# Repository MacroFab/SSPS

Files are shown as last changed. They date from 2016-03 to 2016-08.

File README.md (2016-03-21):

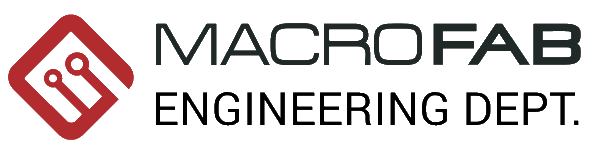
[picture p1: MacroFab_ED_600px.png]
MF_ED_Logo

***
###SSPS
***
**MacroFab, INC. Super Simple Power Supply**

This repository contains the information and files needed to build the Super Simple Power Supply or SSPS. 

More information can be found on the [MacroFab, INC. blog](https://macrofab.com/blog/tag/ssps/). 

***
**License Information**

This project is under the [Creative Commons Attribution-ShareAlike 4.0 International License](LICENSE.md). These files are provided with no warranty and should be used at your own risk. 

***

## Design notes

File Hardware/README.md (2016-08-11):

***
###Hardware
***
**Hardware for the Super Simple Power Supply**

This repository contains the information and files needed to build the Super Simple Power Supply or SSPS. 

More information can be found on the [MacroFab, INC. blog](https://macrofab.com/blog/tag/ssps/). Specifications can be found [here](https://macrofab.com/blog/super-simple-power-supply-ssps-design-part-1/).

***
**License Information**

This project is under the [Creative Commons Attribution-ShareAlike 4.0 International License](LICENSE.md). These files are provided with no warranty and should be used at your own risk. 

***
**Directory listing of the repository**

| Directory | Description |
|---|---|
| Datasheets |  Datasheets that are a pain to get a hold of. |
| Enclosure | Enclosure Drawings and Mockups. | 
| OPA541 Breakout | Test board for the OPA541 Opamp. |
| SSPS Front Panel | Front Panel for the SSPS. Digital Controls. |
| SSPS Front Panel Test | Test board for the SSPS digital side. |
| SSPS Analog board | Analog output board |
| SSPS Regulated Power Supply Simulation | Multisim Simulation of the SSPS Analog side. |

***
**Credits**

Designed by:   
Parker Dillmann 
Stephen "Hackerman" Kraig 

Software by:   
Parker Dillmann  
Stephen "Hackerman" Kraig 

***

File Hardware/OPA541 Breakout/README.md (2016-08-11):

###OPA541AP Breakout
***
**A simple breakout PCB for testing the OPA541 Opamp**

***
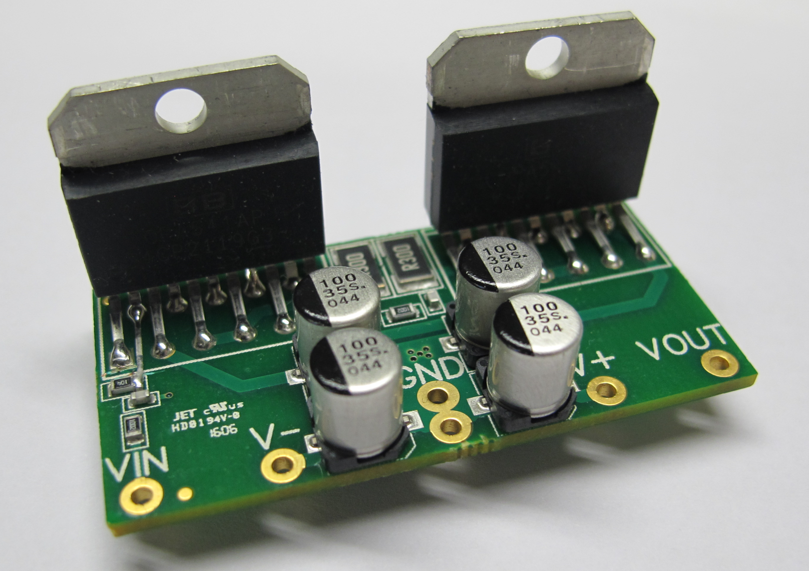
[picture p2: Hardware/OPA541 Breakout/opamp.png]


***
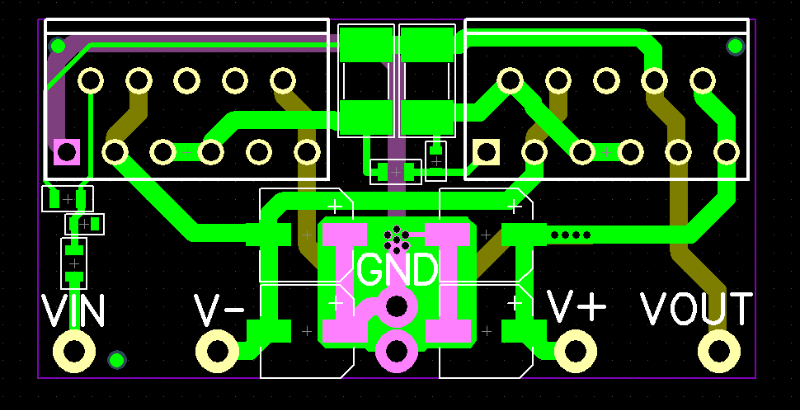
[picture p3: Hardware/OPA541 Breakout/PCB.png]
Layout Image


***
Schematic Image

***
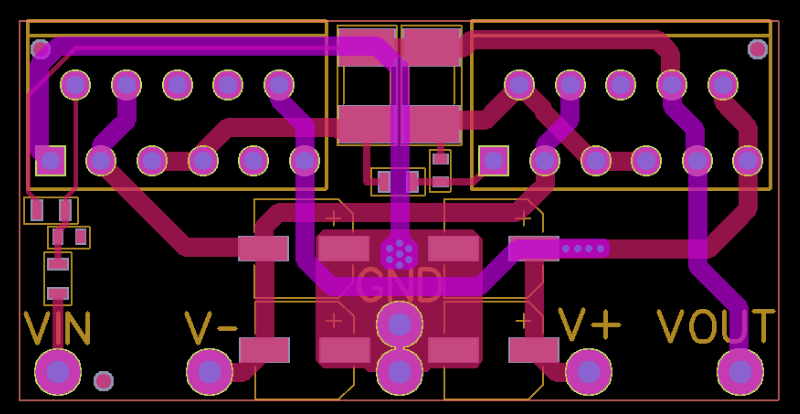
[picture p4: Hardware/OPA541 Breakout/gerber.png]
Gerber Top Drawing


Files are for Diptrace 2.4. Gerber files can be found in the Manufacturing Files directory. See main directory for licensing.

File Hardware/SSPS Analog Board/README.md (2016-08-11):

###SSPS Analog Output PCB
***
**The first revision of the analog output PCB for the SSPS**

***
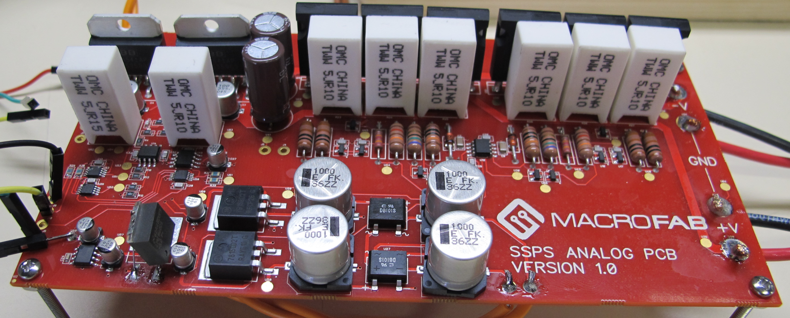
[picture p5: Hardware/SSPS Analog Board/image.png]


***
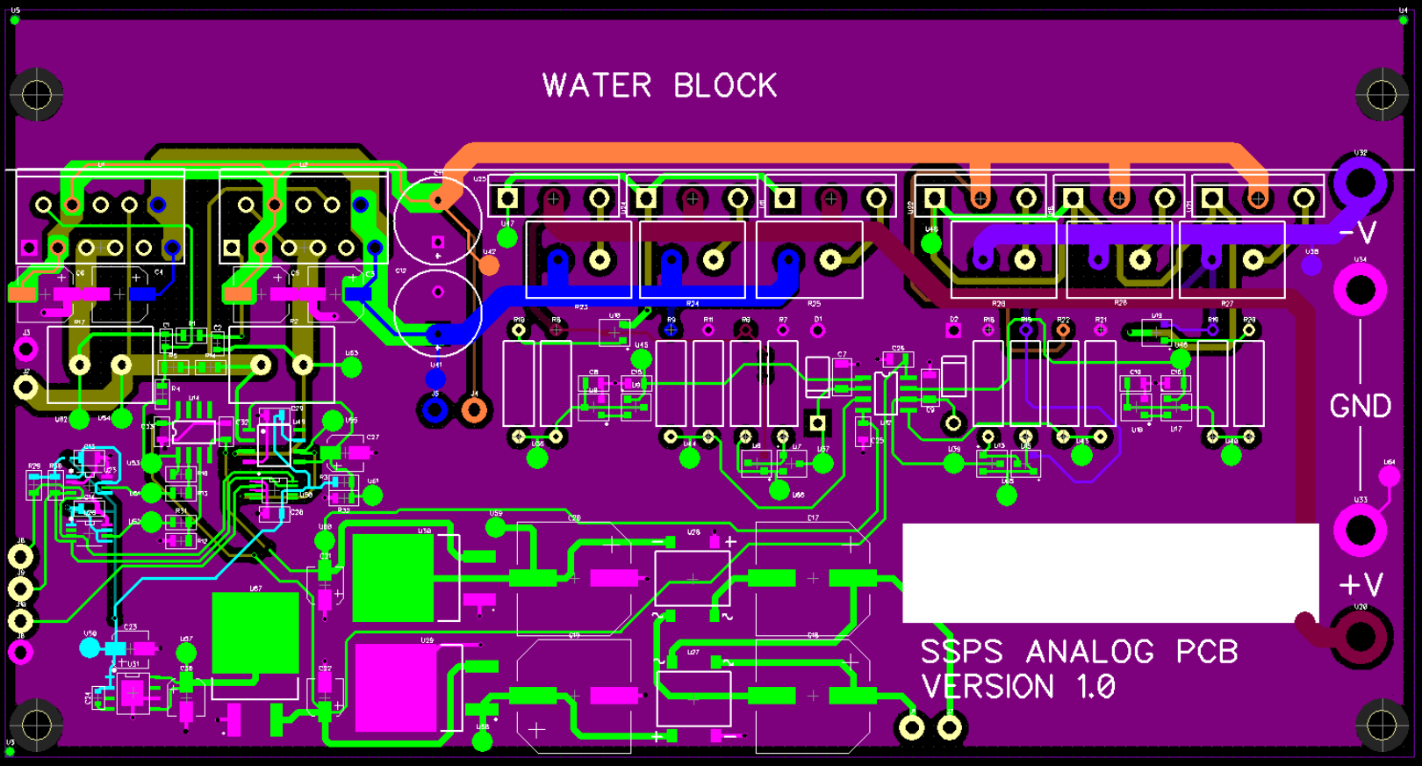
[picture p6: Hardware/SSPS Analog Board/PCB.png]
Layout Image


***
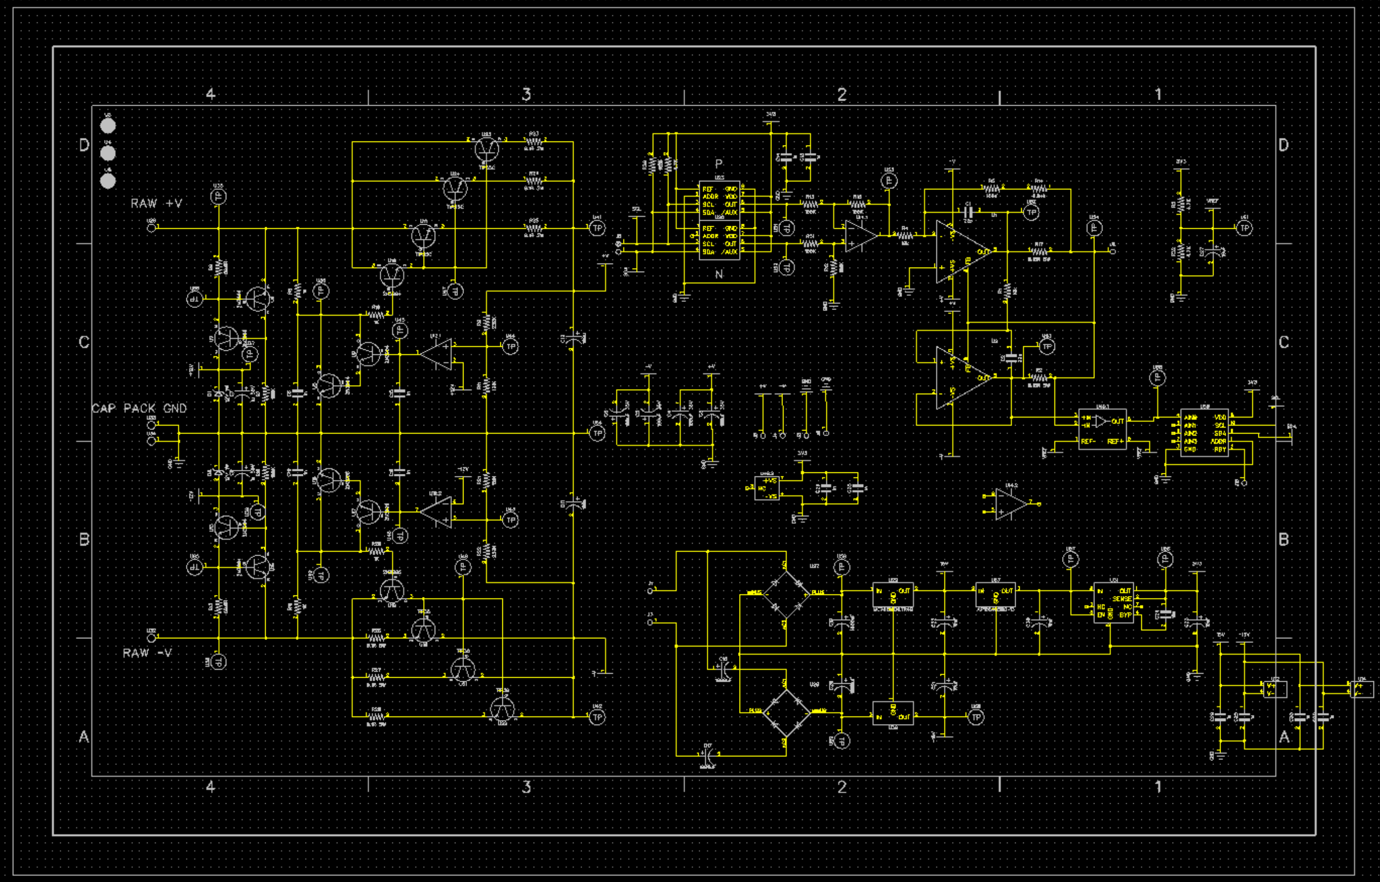
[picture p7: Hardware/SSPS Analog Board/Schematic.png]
Schematic Image


***
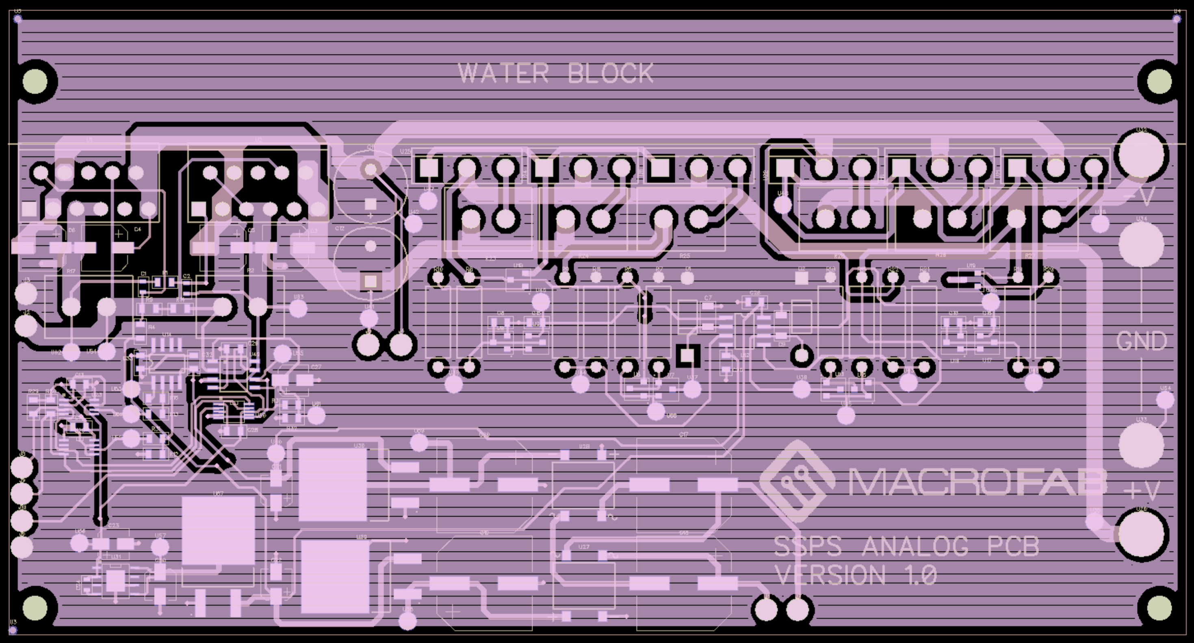
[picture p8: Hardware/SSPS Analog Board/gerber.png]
Gerber Top Drawing


Files are for Diptrace 2.4. Gerber files can be found in the Manufacturing Files directory. See main directory for licensing.

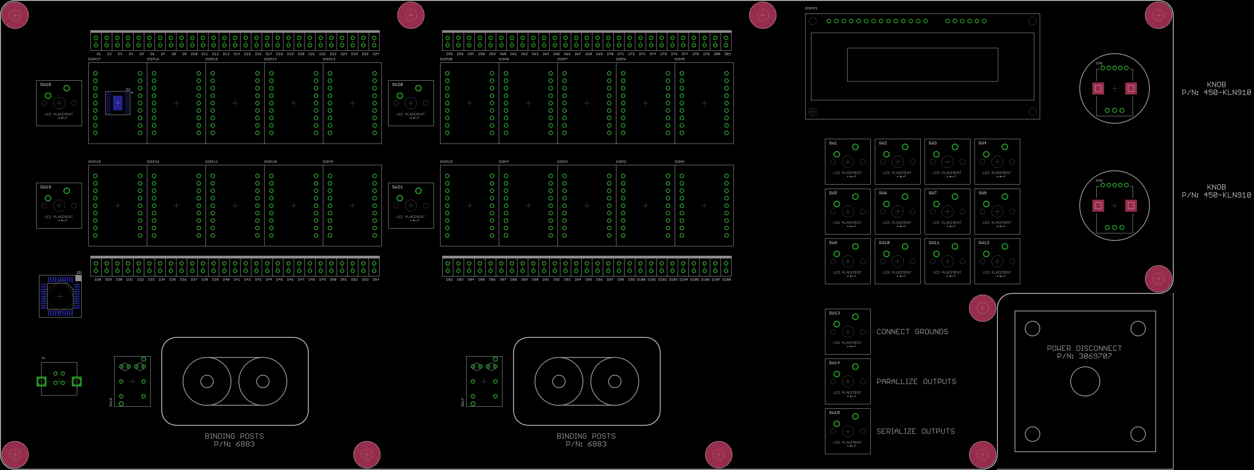
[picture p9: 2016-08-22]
Hardware/SSPS Front Panel/Layout.png

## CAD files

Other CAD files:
Hardware/SSPS Front Panel/SSPS Front Panel.dwg
Hardware/Enclosure/Enclosure.skp

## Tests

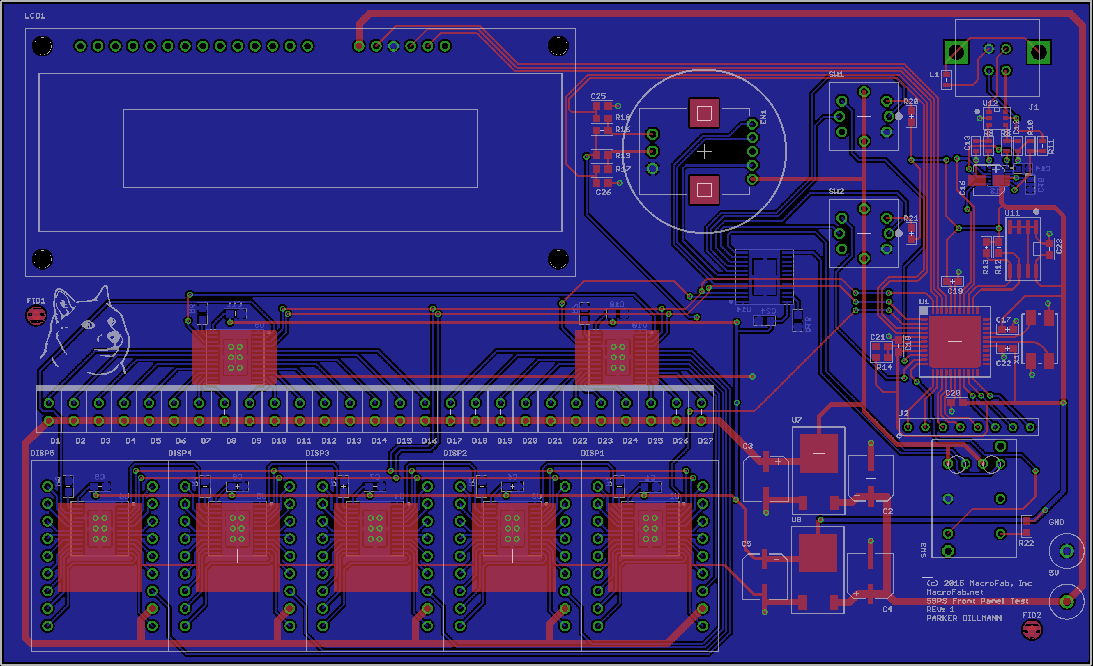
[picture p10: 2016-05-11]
Hardware/SSPS Front Panel Test/Layout.png

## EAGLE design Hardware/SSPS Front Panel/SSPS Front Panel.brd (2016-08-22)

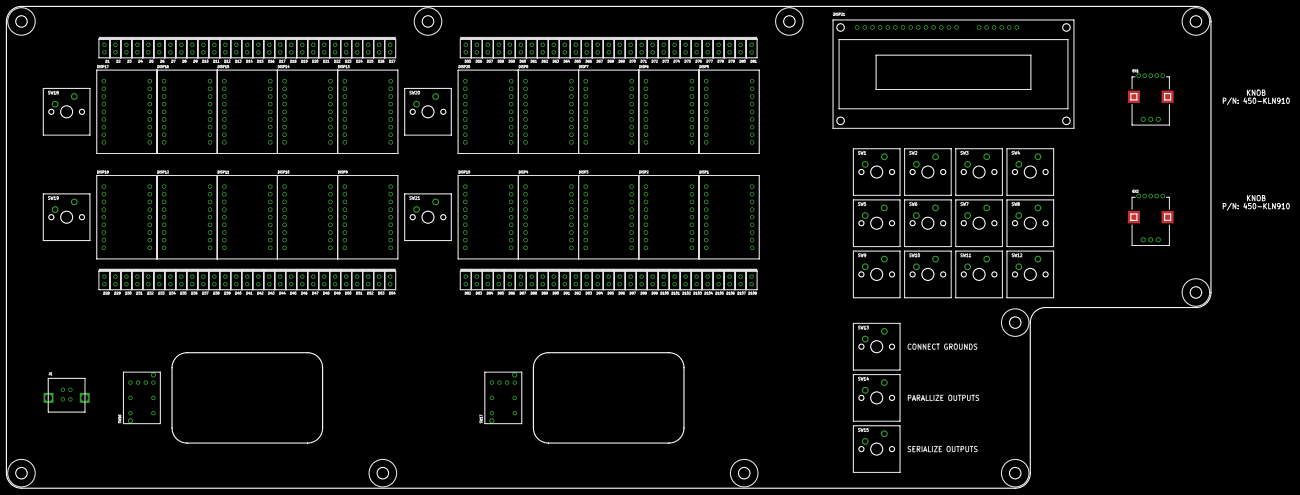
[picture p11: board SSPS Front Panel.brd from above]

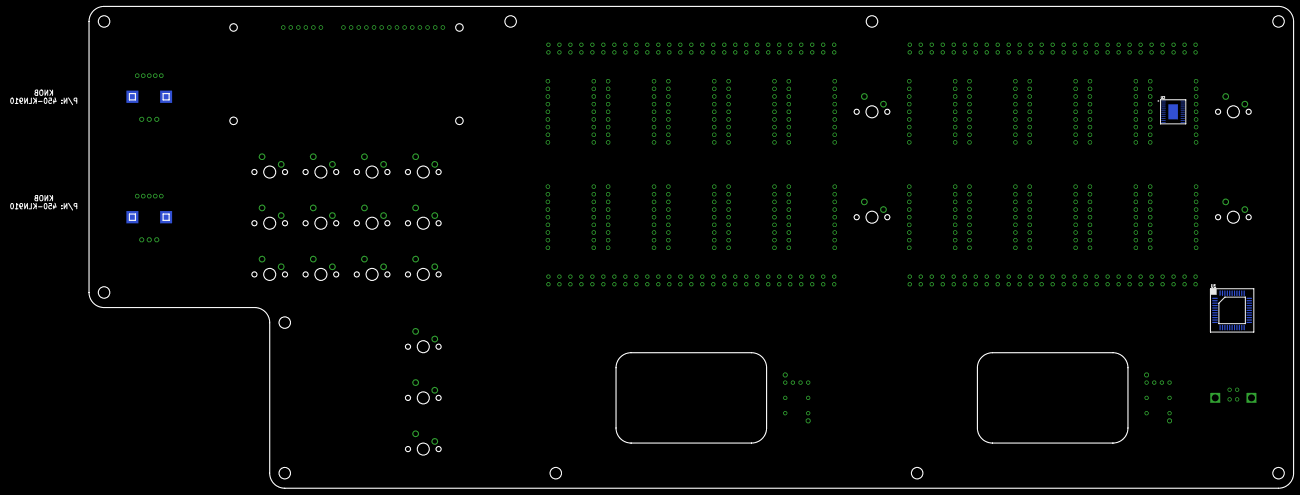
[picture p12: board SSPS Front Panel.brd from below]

Board: 2 copper layers, 400.0 x 160.0 mm, 165 parts (2 on the bottom side), 3 nets, no tracks yet.

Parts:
D1, D2, D3, D4, D5, D6, D7, D8, D9, D10, D11, D12, D13, D14, D15, D16, D17, D18, D19, D20, D21, D22, D23, D24, D25, D26, D27, D28, D29, D30, D31, D32, D33, D34, D35, D36, D37, D38, D39, D40, D41, D42, D43, D44, D45, D46, D47, D48, D49, D50, D51, D52, D53, D54, D55, D56, D57, D58, D59, D60, D61, D62, D63, D64, D65, D66, D67, D68, D69, D70, D71, D72, D73, D74, D75, D76, D77, D78, D79, D80, D81, D82, D83, D84, D85, D86, D87, D88, D89, D90, D91, D92, D93, D94, D95, D96, D97, D98, D99, D100, D101, D102, D103, D104, D105, D106, D107, D108: WP1043
DISP1, DISP2, DISP3, DISP4, DISP5, DISP6, DISP7, DISP8, DISP9, DISP10, DISP11, DISP12, DISP13, DISP14, DISP15, DISP16, DISP17, DISP18, DISP19, DISP20: PSA08-11GWA; PSA08-11SRWA
DISP21: CU16025-UWJ6; CU16025-UW6J
EN1, EN2: PEL12T-4226F-S1024; PEL12T
H1, H2, H3, H4, H5, H6, H7, H8, H9, H10: MOUNT_HOLE_150MIL
J1: 61400413321
SW1, SW2, SW3, SW4, SW5, SW6, SW7, SW8, SW9, SW10, SW11, SW12, SW13, SW14, SW15, SW18, SW19, SW20, SW21: MX1A
SW16, SW17: 5501
U1: P8X32A-Q44; LQFP44
U2: STP16CP05XTTR; STP16CP05XTTR_TTSOP-24

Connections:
SLD: J1.S1, J1.S2
VDD: U1.8, U1.18, U1.30, U1.40
VSS: U1.5, U1.17, U1.27, U1.39

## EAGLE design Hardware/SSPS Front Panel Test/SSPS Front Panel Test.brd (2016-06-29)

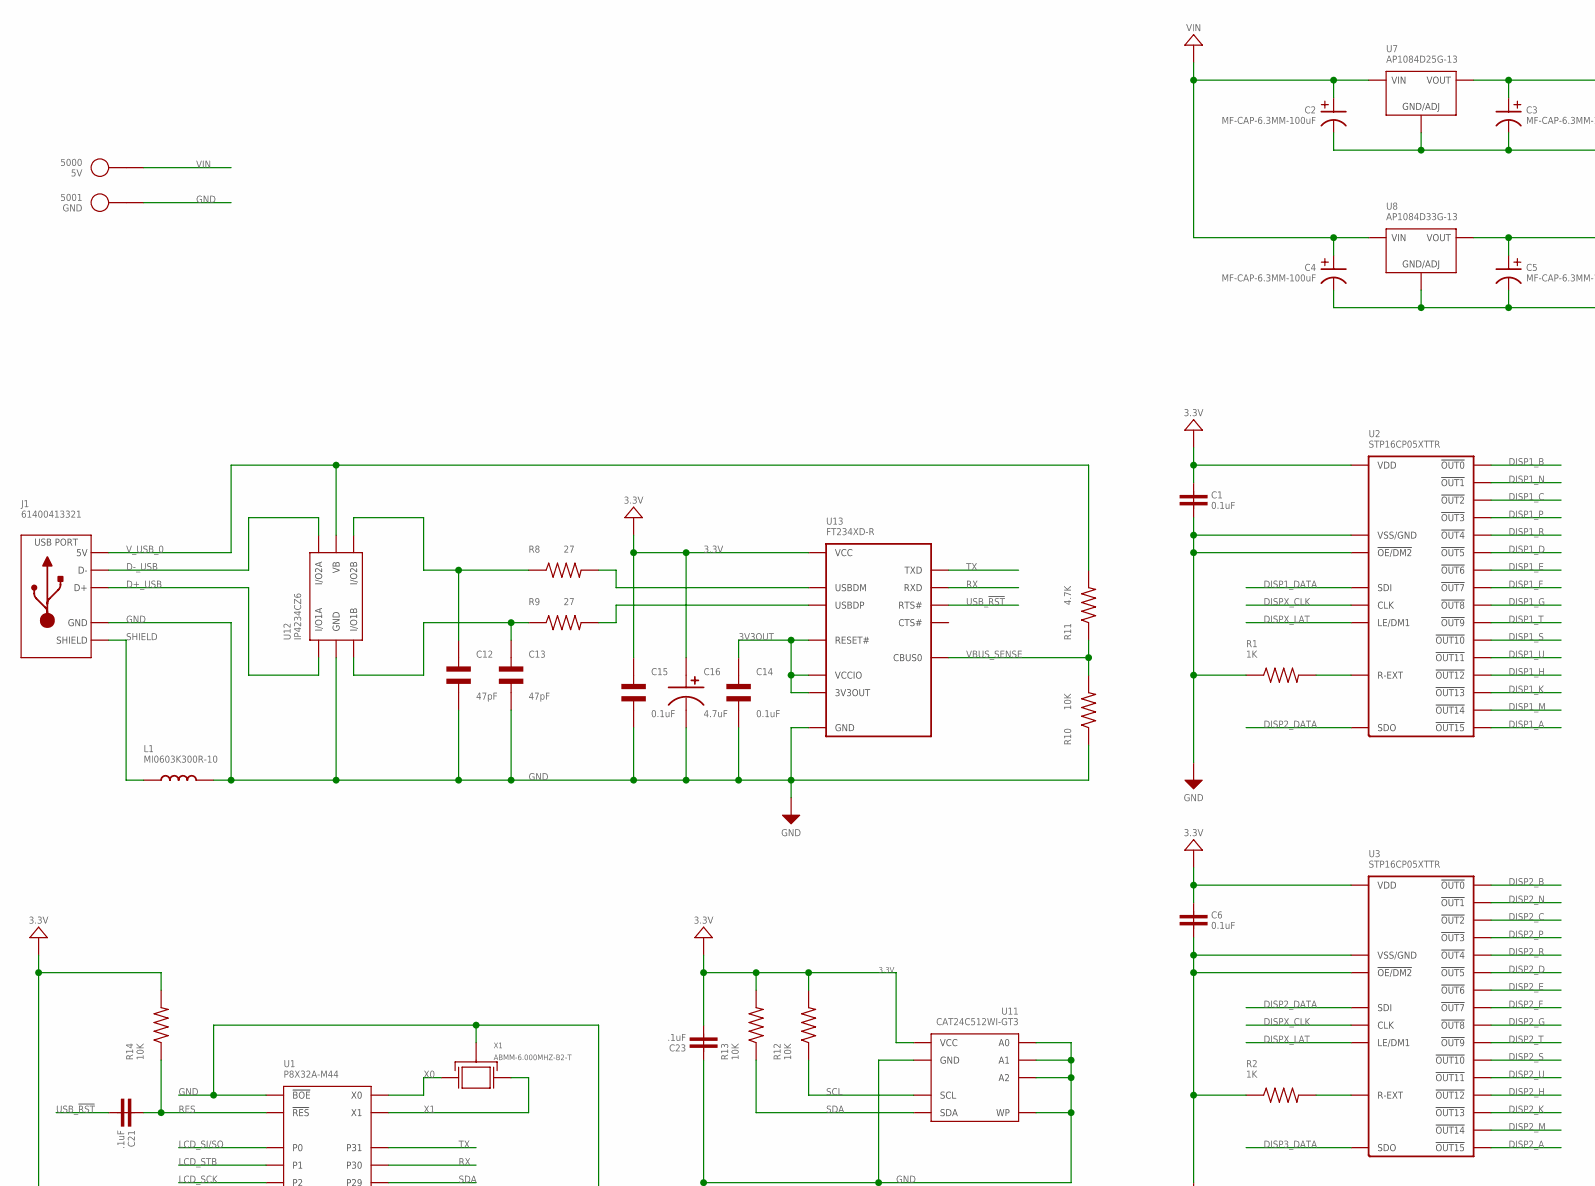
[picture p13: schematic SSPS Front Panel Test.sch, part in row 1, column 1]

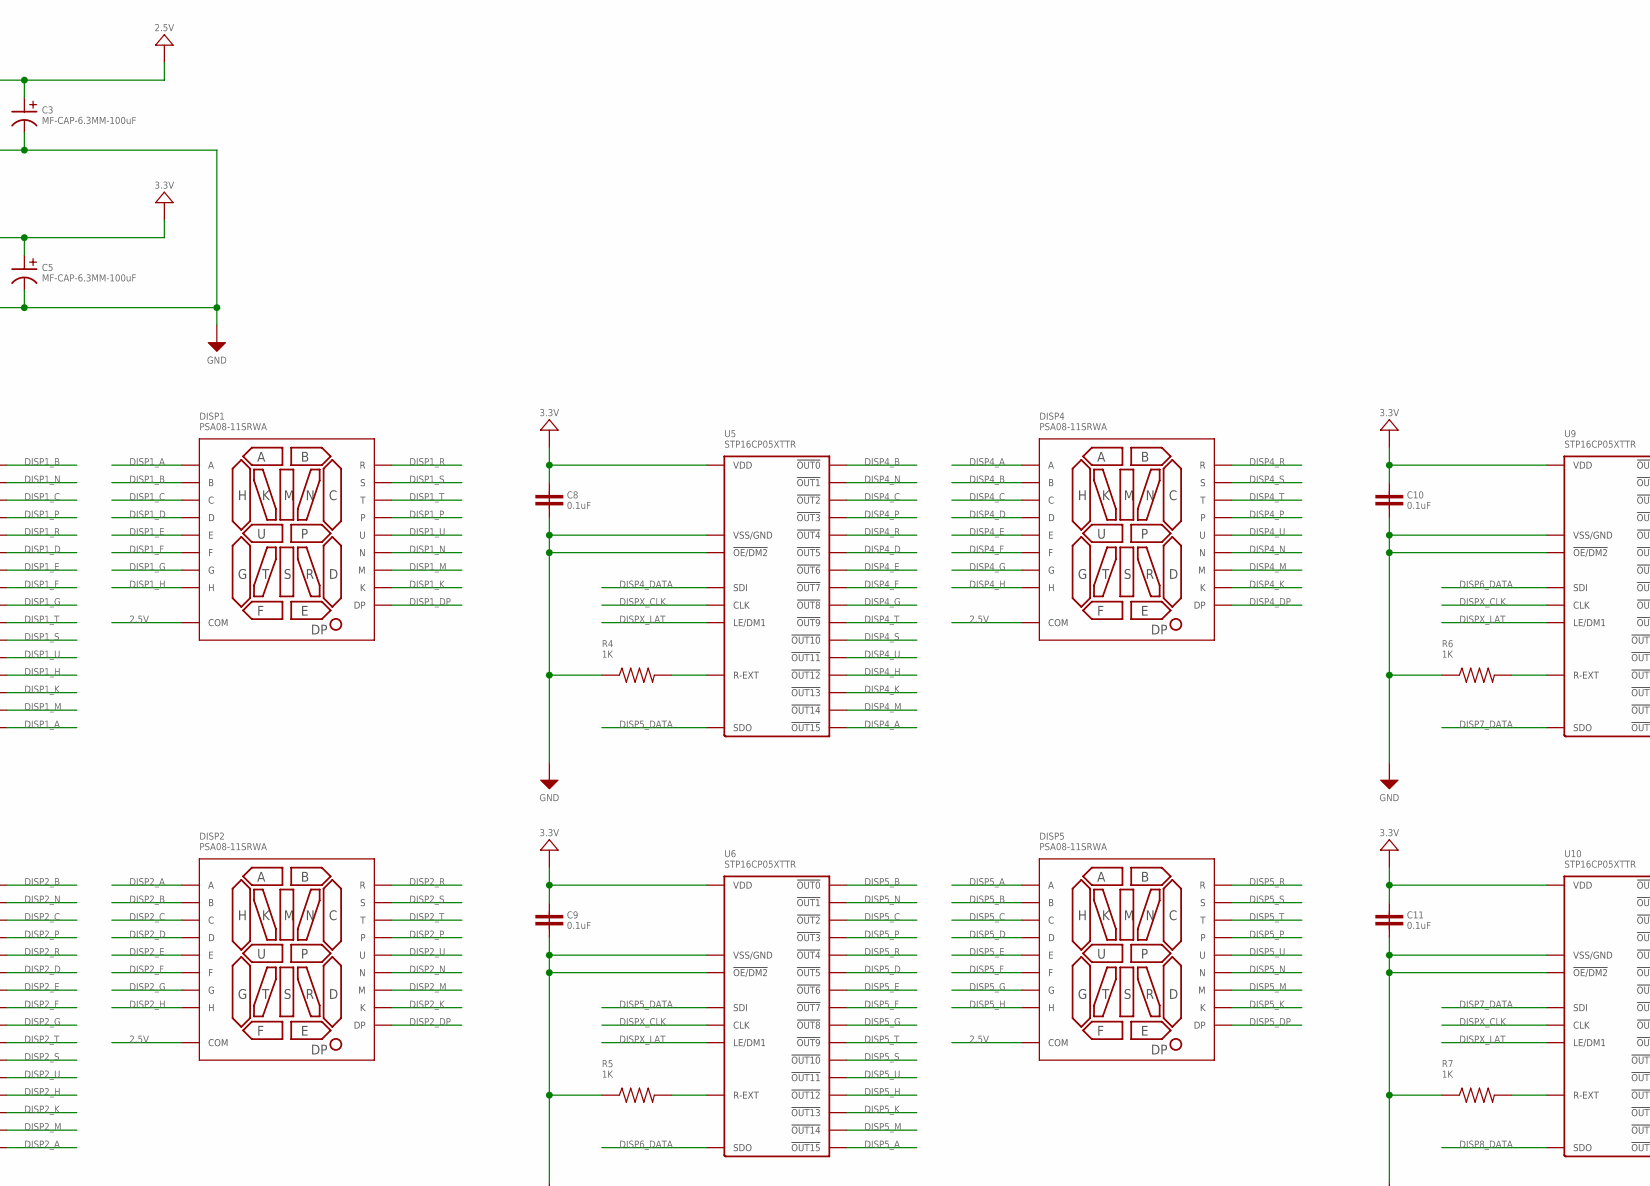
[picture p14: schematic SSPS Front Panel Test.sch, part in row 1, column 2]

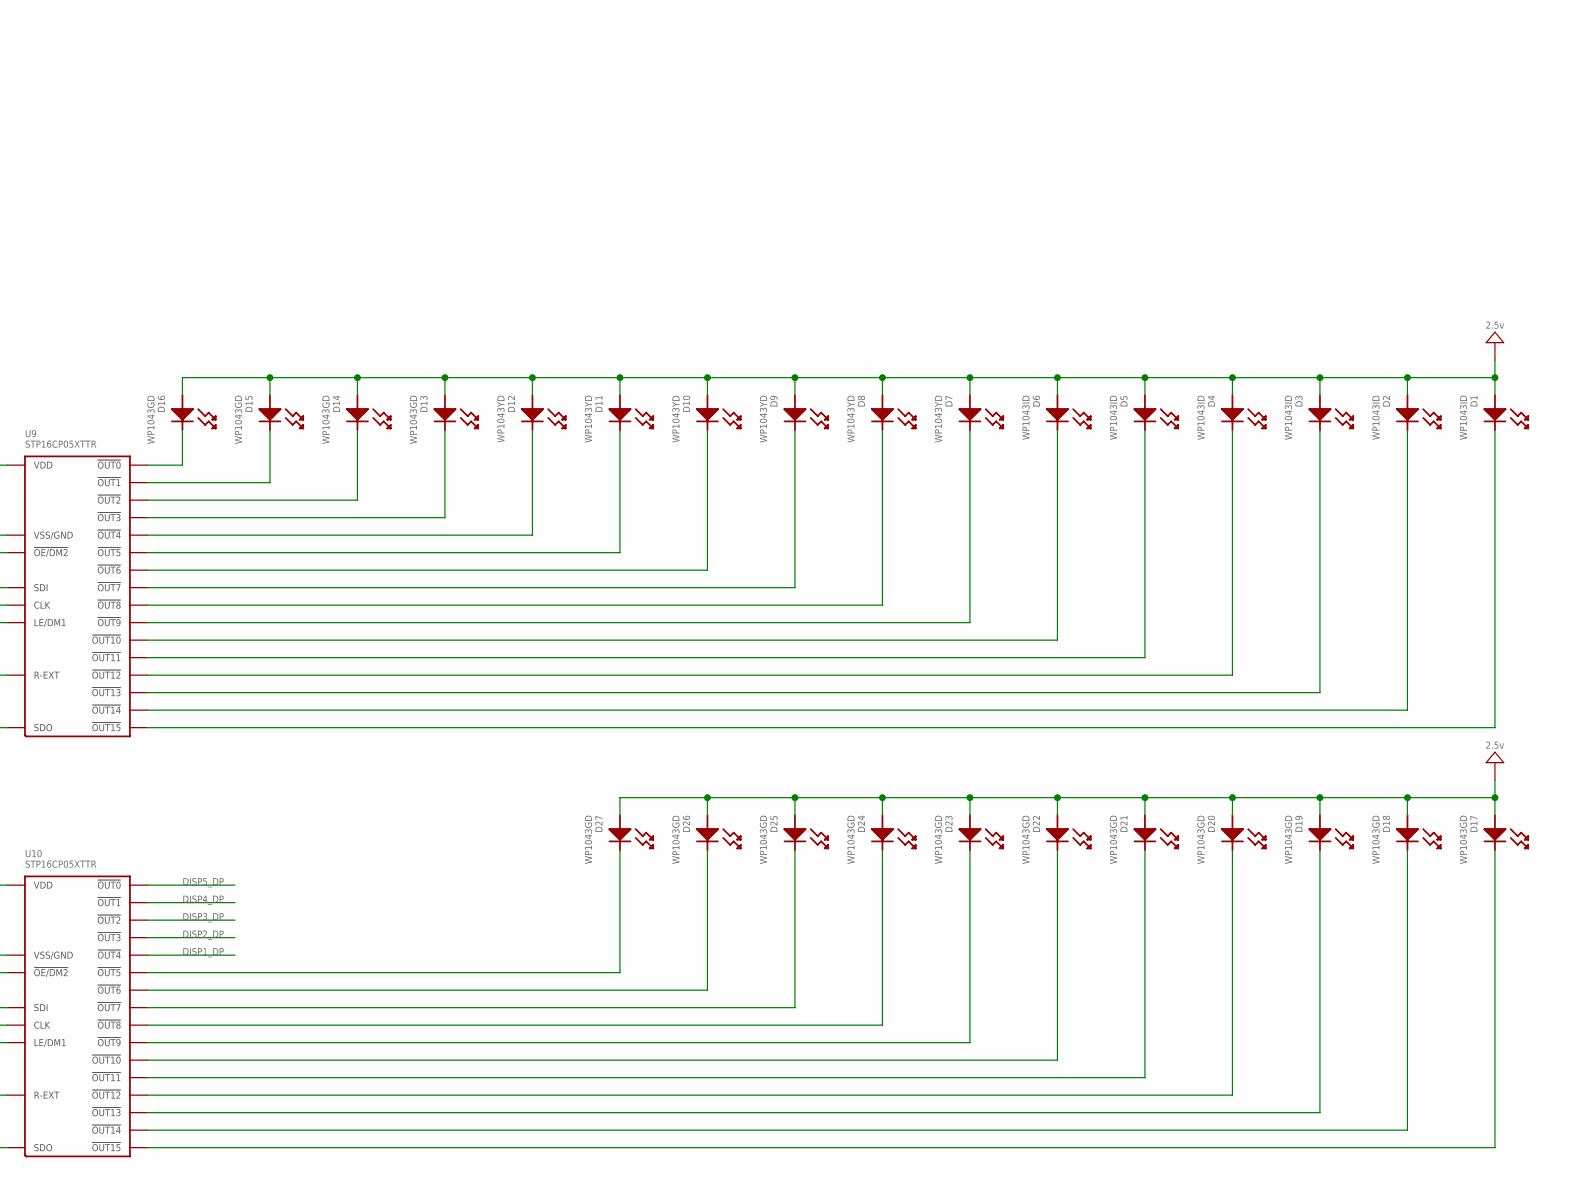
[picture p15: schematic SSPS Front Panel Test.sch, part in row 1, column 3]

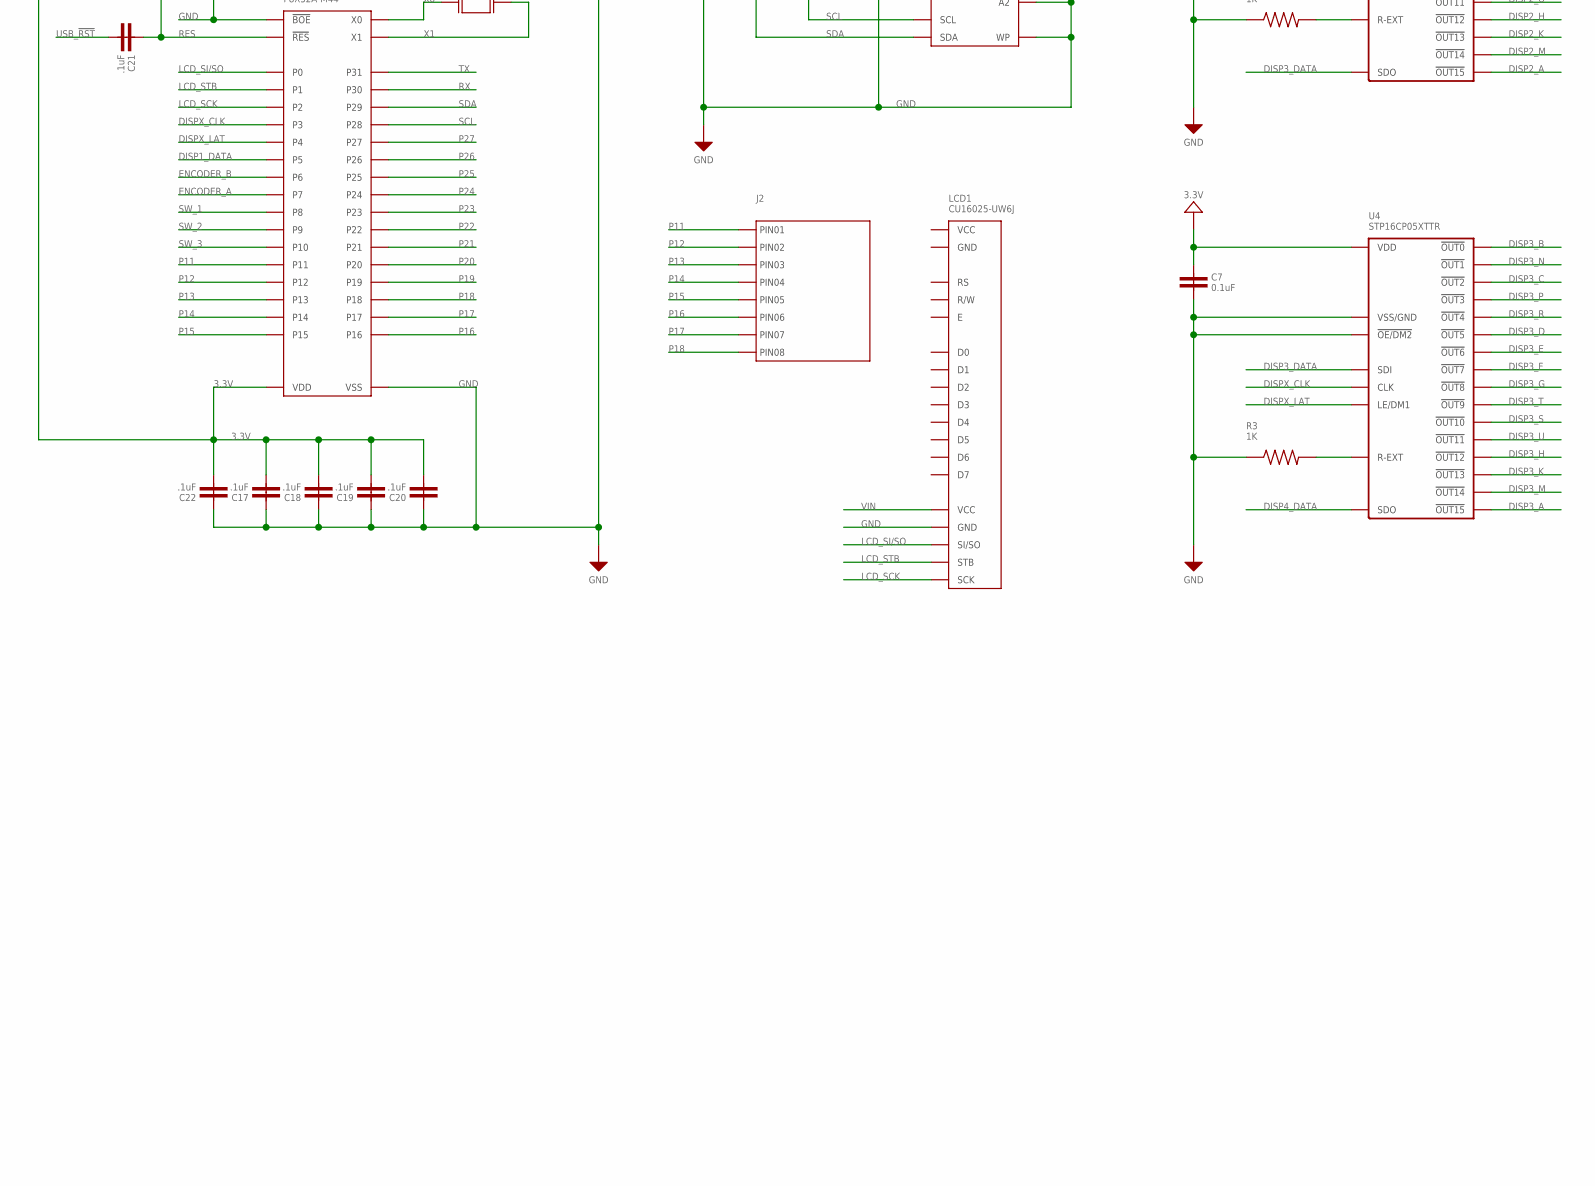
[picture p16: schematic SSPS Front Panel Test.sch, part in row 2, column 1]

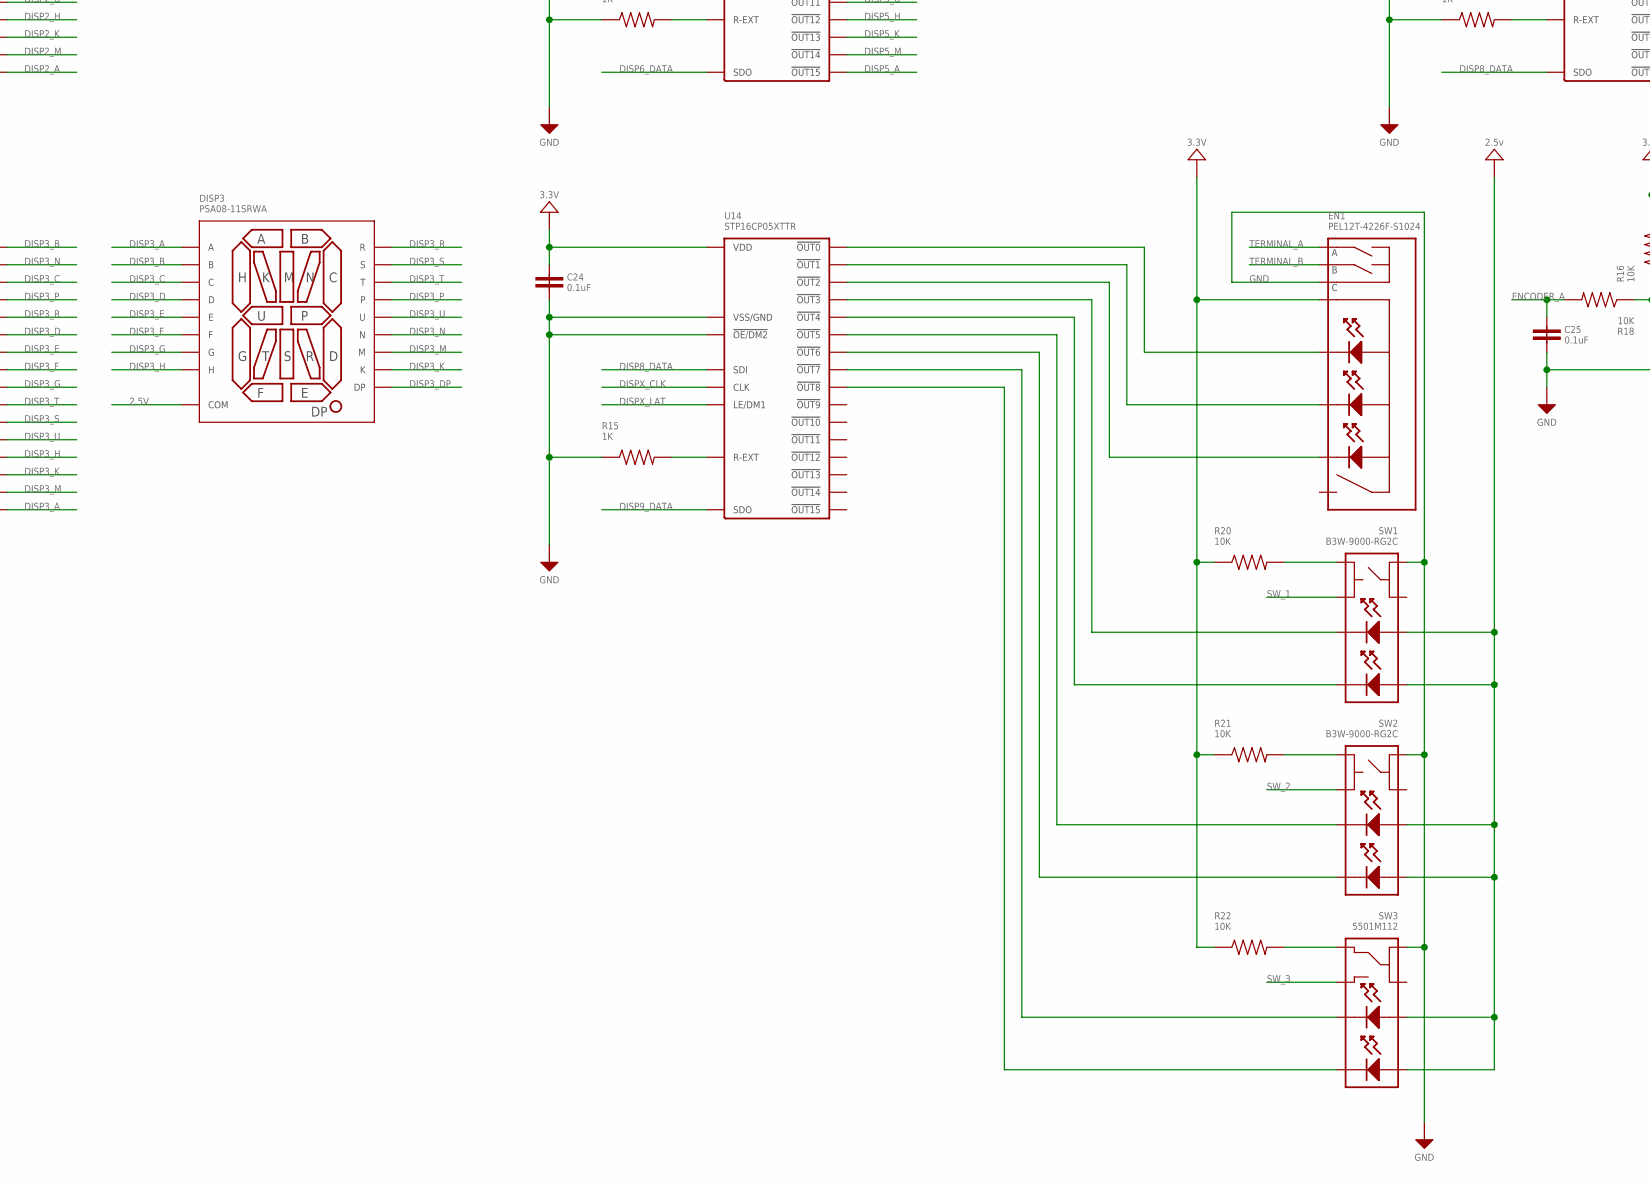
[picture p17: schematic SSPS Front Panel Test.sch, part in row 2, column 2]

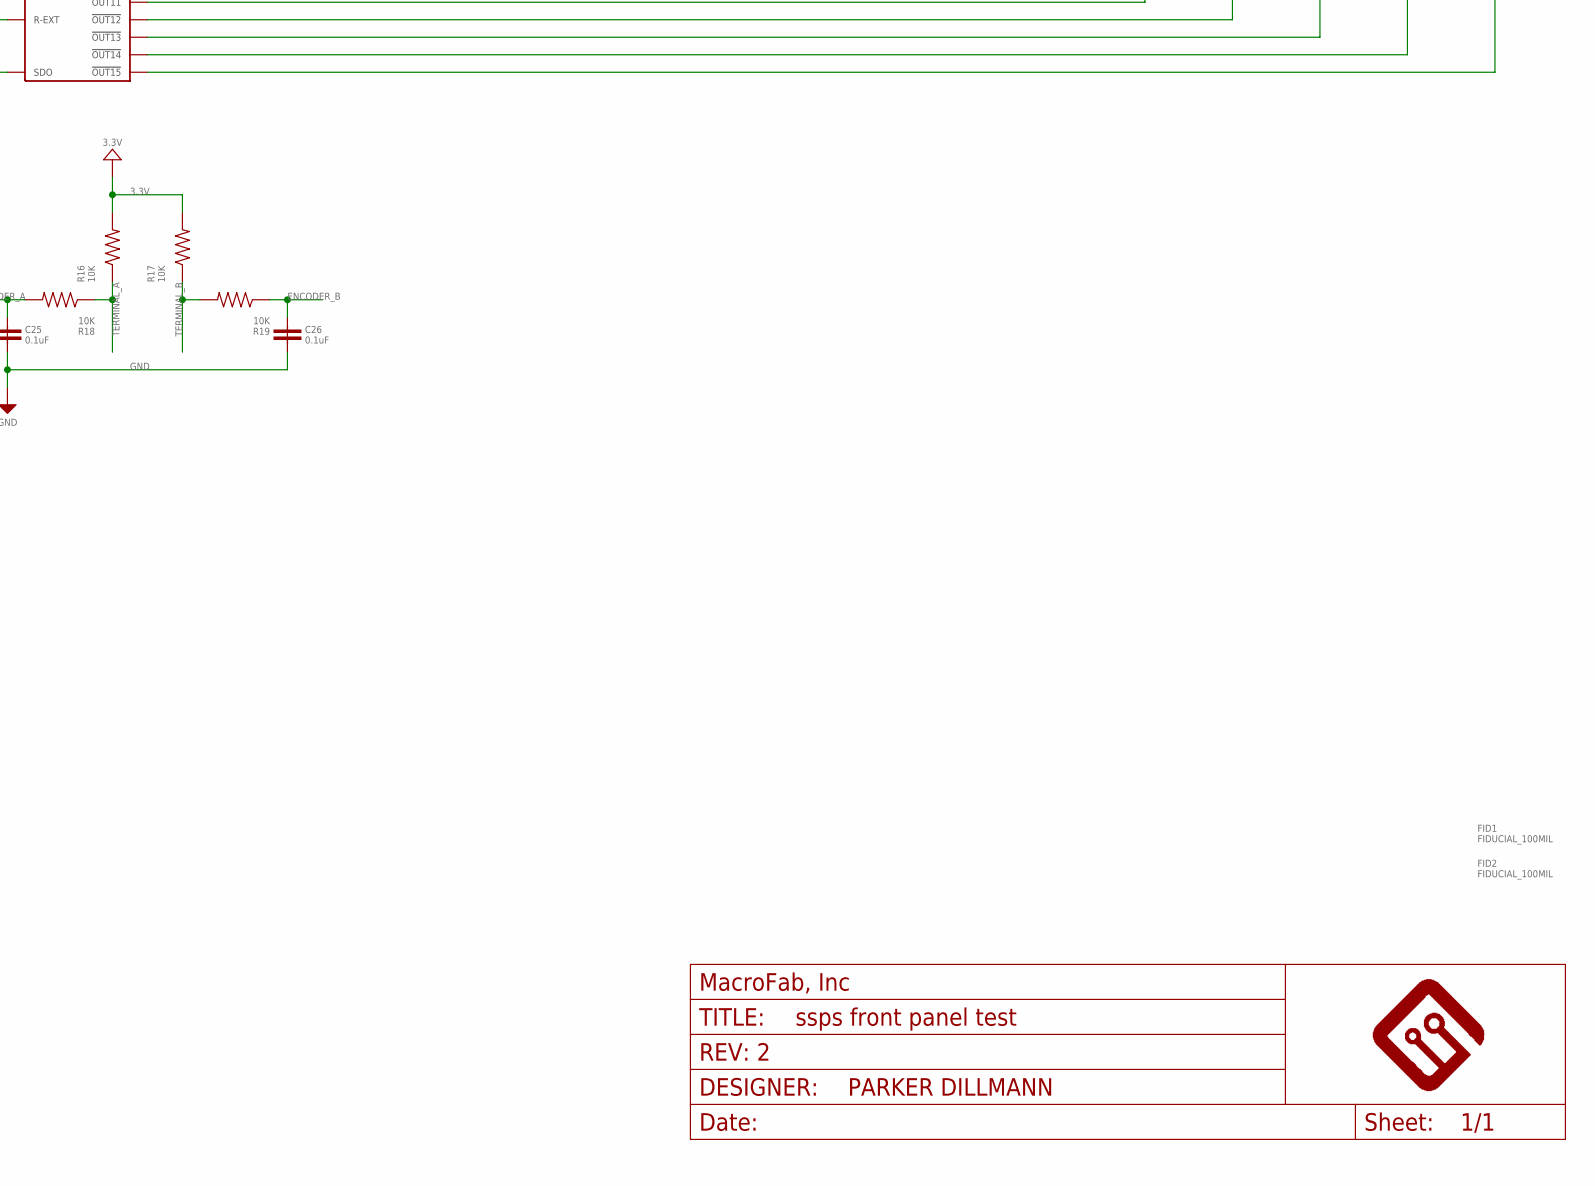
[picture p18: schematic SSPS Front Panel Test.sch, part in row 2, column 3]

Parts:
5V: 5000; KEYSTONE_5115-5119
C1, C6, C7, C8, C9, C10, C11, C24, C25, C26: 0.1uF; 0603
C2, C3, C4, C5: MF-CAP-6.3MM-100uF; 6.3MM_CAP_SMD
C12, C13: 47pF; C0603
C14, C15: 0.1uF; C0603
C16: 4.7uF; CP4MM
C17, C18, C19, C20, C21, C22, C23: .1uF; 0603
D1, D2, D3, D4, D5, D6: WP1043ID; WP1043
D7, D8, D9, D10, D11, D12: WP1043YD; WP1043
D13, D14, D15, D16, D17, D18, D19, D20, D21, D22, D23, D24, D25, D26, D27: WP1043GD; WP1043
DISP1, DISP2, DISP3, DISP4, DISP5: PSA08-11SRWA
EN1: PEL12T-4226F-S1024; PEL12T
FID1, FID2: FIDUCIAL_100MIL
FRAME1: MF_FRAMEDEFAULT; MF_FRAME_DEFAULT
GND: 5001; KEYSTONE_5115-5119
J1: 61400413321
J2: CON_01X08_2.54MM_PIN_HEADER; 2.54MM_01X08_PIN_HEADER
L1: MI0603K300R-10; L0603
LCD1: CU16025-UW6J
R1, R2, R3, R4, R5, R6, R7, R15: 1K; 0603
R8, R9: 27; R0603
R10: 10K; R0603
R11: 4.7K; R0603
R12, R13, R14, R16, R17, R18, R19, R20, R21, R22: 10K; 0603
SW1, SW2: B3W-9000-RG2C; B3W-9000
SW3: 5501M112; 5501
U1: P8X32A-M44; P8X32A_QFN-44
U2, U3, U4, U5, U6, U9, U10, U14: STP16CP05XTTR; STP16CP05XTTR_TTSOP-24
U7: AP1084D25G-13; AP1084_TO-252-3L
U8: AP1084D33G-13; AP1084_TO-252-3L
U11: CAT24C512WI-GT3; SOIC-8_W
U12: IP4234CZ6; IP4234CZ6_SOT-457-6
U13: FT234XD-R; FT234X_DFN-12
X1: ABMM-6.000MHZ-B2-T; 7MMX5MM

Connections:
2.5V: C3.POS, D1.A (ANODE), D2.A (ANODE), D3.A (ANODE), D4.A (ANODE), D5.A (ANODE), D6.A (ANODE), D7.A (ANODE), D8.A (ANODE), D9.A (ANODE), D10.A (ANODE), D11.A (ANODE), D12.A (ANODE), D13.A (ANODE), D14.A (ANODE), D15.A (ANODE), D16.A (ANODE), D17.A (ANODE), D18.A (ANODE), D19.A (ANODE), D20.A (ANODE), D21.A (ANODE), D22.A (ANODE), D23.A (ANODE), D24.A (ANODE), D25.A (ANODE), D26.A (ANODE), D27.A (ANODE), DISP1.P$11 (COM), DISP2.P$11 (COM), DISP3.P$11 (COM), DISP4.P$11 (COM), DISP5.P$11 (COM), SW1.ANODE_1, SW1.ANODE_2, SW2.ANODE_1, SW2.ANODE_2, SW3.ANODE_1, SW3.ANODE_2, U7.3 (OUT)
3.3V: C1.1, C5.POS, C6.1, C7.1, C8.1, C9.1, C10.1, C11.1, C15.P$1, C16.P$1, C17.2, C18.2, C19.2, C20.2, C22.2, C23.2, C24.1, EN1.5, R12.2, R13.2, R14.2, R16.2, R17.2, R20.1, R21.1, R22.1, U1.8 (VDD), U1.18 (VDD), U1.30 (VDD), U1.40 (VDD), U2.P$24 (VDD), U3.P$24 (VDD), U4.P$24 (VDD), U5.P$24 (VDD), U6.P$24 (VDD), U8.3 (OUT), U9.P$24 (VDD), U10.P$24 (VDD), U11.8 (VCC), U13.4 (VCC), U14.P$24 (VDD)
3V3OUT: C14.P$1, U13.2 (RESET#), U13.3 (3V3OUT), U13.9 (VCCIO)
D+_USB: J1.3 (D+), U12.1 (I/O1A)
D-_USB: J1.2 (D-), U12.6 (I/O2A)
DISP1_A: DISP1.P$1 (A), U2.P$20 (!OUT15)
DISP1_B: DISP1.P$18 (B), U2.P$5 (!OUT0)
DISP1_C: DISP1.P$16 (C), U2.P$7 (!OUT2)
DISP1_D: DISP1.P$13 (D), U2.P$10 (!OUT5)
DISP1_DATA: U1.2 (P5), U2.P$2 (SDI)
DISP1_DP: DISP1.P$12 (DP), U10.P$9 (!OUT4)
DISP1_E: DISP1.P$10 (E), U2.P$11 (!OUT6)
DISP1_F: DISP1.P$9 (F), U2.P$12 (!OUT7)
DISP1_G: DISP1.P$8 (G), U2.P$13 (!OUT8)
DISP1_H: DISP1.P$4 (H), U2.P$17 (!OUT12)
DISP1_K: DISP1.P$3 (K), U2.P$18 (!OUT13)
DISP1_M: DISP1.P$2 (M), U2.P$19 (!OUT14)
DISP1_N: DISP1.P$17 (N), U2.P$6 (!OUT1)
DISP1_P: DISP1.P$15, U2.P$8 (!OUT3)
DISP1_R: DISP1.P$14 (R), U2.P$9 (!OUT4)
DISP1_S: DISP1.P$6 (S), U2.P$15 (!OUT10)
DISP1_T: DISP1.P$7 (T), U2.P$14 (!OUT9)
DISP1_U: DISP1.P$5 (U), U2.P$16 (!OUT11)
DISP2_A: DISP2.P$1 (A), U3.P$20 (!OUT15)
DISP2_B: DISP2.P$18 (B), U3.P$5 (!OUT0)
DISP2_C: DISP2.P$16 (C), U3.P$7 (!OUT2)
DISP2_D: DISP2.P$13 (D), U3.P$10 (!OUT5)
DISP2_DATA: U2.P$22 (SDO), U3.P$2 (SDI)
DISP2_DP: DISP2.P$12 (DP), U10.P$8 (!OUT3)
DISP2_E: DISP2.P$10 (E), U3.P$11 (!OUT6)
DISP2_F: DISP2.P$9 (F), U3.P$12 (!OUT7)
DISP2_G: DISP2.P$8 (G), U3.P$13 (!OUT8)
DISP2_H: DISP2.P$4 (H), U3.P$17 (!OUT12)
DISP2_K: DISP2.P$3 (K), U3.P$18 (!OUT13)
DISP2_M: DISP2.P$2 (M), U3.P$19 (!OUT14)
DISP2_N: DISP2.P$17 (N), U3.P$6 (!OUT1)
DISP2_P: DISP2.P$15, U3.P$8 (!OUT3)
DISP2_R: DISP2.P$14 (R), U3.P$9 (!OUT4)
DISP2_S: DISP2.P$6 (S), U3.P$15 (!OUT10)
DISP2_T: DISP2.P$7 (T), U3.P$14 (!OUT9)
DISP2_U: DISP2.P$5 (U), U3.P$16 (!OUT11)
DISP3_A: DISP3.P$1 (A), U4.P$20 (!OUT15)
DISP3_B: DISP3.P$18 (B), U4.P$5 (!OUT0)
DISP3_C: DISP3.P$16 (C), U4.P$7 (!OUT2)
DISP3_D: DISP3.P$13 (D), U4.P$10 (!OUT5)
DISP3_DATA: U3.P$22 (SDO), U4.P$2 (SDI)
DISP3_DP: DISP3.P$12 (DP), U10.P$7 (!OUT2)
DISP3_E: DISP3.P$10 (E), U4.P$11 (!OUT6)
DISP3_F: DISP3.P$9 (F), U4.P$12 (!OUT7)
DISP3_G: DISP3.P$8 (G), U4.P$13 (!OUT8)
DISP3_H: DISP3.P$4 (H), U4.P$17 (!OUT12)
DISP3_K: DISP3.P$3 (K), U4.P$18 (!OUT13)
DISP3_M: DISP3.P$2 (M), U4.P$19 (!OUT14)
DISP3_N: DISP3.P$17 (N), U4.P$6 (!OUT1)
DISP3_P: DISP3.P$15, U4.P$8 (!OUT3)
DISP3_R: DISP3.P$14 (R), U4.P$9 (!OUT4)
DISP3_S: DISP3.P$6 (S), U4.P$15 (!OUT10)
DISP3_T: DISP3.P$7 (T), U4.P$14 (!OUT9)
DISP3_U: DISP3.P$5 (U), U4.P$16 (!OUT11)
DISP4_A: DISP4.P$1 (A), U5.P$20 (!OUT15)
DISP4_B: DISP4.P$18 (B), U5.P$5 (!OUT0)
DISP4_C: DISP4.P$16 (C), U5.P$7 (!OUT2)
DISP4_D: DISP4.P$13 (D), U5.P$10 (!OUT5)
DISP4_DATA: U4.P$22 (SDO), U5.P$2 (SDI)
DISP4_DP: DISP4.P$12 (DP), U10.P$6 (!OUT1)
DISP4_E: DISP4.P$10 (E), U5.P$11 (!OUT6)
DISP4_F: DISP4.P$9 (F), U5.P$12 (!OUT7)
DISP4_G: DISP4.P$8 (G), U5.P$13 (!OUT8)
DISP4_H: DISP4.P$4 (H), U5.P$17 (!OUT12)
DISP4_K: DISP4.P$3 (K), U5.P$18 (!OUT13)
DISP4_M: DISP4.P$2 (M), U5.P$19 (!OUT14)
DISP4_N: DISP4.P$17 (N), U5.P$6 (!OUT1)
DISP4_P: DISP4.P$15, U5.P$8 (!OUT3)
DISP4_R: DISP4.P$14 (R), U5.P$9 (!OUT4)
DISP4_S: DISP4.P$6 (S), U5.P$15 (!OUT10)
DISP4_T: DISP4.P$7 (T), U5.P$14 (!OUT9)
DISP4_U: DISP4.P$5 (U), U5.P$16 (!OUT11)
DISP5_A: DISP5.P$1 (A), U6.P$20 (!OUT15)
DISP5_B: DISP5.P$18 (B), U6.P$5 (!OUT0)
DISP5_C: DISP5.P$16 (C), U6.P$7 (!OUT2)
DISP5_D: DISP5.P$13 (D), U6.P$10 (!OUT5)
DISP5_DATA: U5.P$22 (SDO), U6.P$2 (SDI)
DISP5_DP: DISP5.P$12 (DP), U10.P$5 (!OUT0)
DISP5_E: DISP5.P$10 (E), U6.P$11 (!OUT6)
DISP5_F: DISP5.P$9 (F), U6.P$12 (!OUT7)
DISP5_G: DISP5.P$8 (G), U6.P$13 (!OUT8)
DISP5_H: DISP5.P$4 (H), U6.P$17 (!OUT12)
DISP5_K: DISP5.P$3 (K), U6.P$18 (!OUT13)
DISP5_M: DISP5.P$2 (M), U6.P$19 (!OUT14)
DISP5_N: DISP5.P$17 (N), U6.P$6 (!OUT1)
DISP5_P: DISP5.P$15, U6.P$8 (!OUT3)
DISP5_R: DISP5.P$14 (R), U6.P$9 (!OUT4)
DISP5_S: DISP5.P$6 (S), U6.P$15 (!OUT10)
DISP5_T: DISP5.P$7 (T), U6.P$14 (!OUT9)
DISP5_U: DISP5.P$5 (U), U6.P$16 (!OUT11)
DISP6_DATA: U6.P$22 (SDO), U9.P$2 (SDI)
DISP7_DATA: U9.P$22 (SDO), U10.P$2 (SDI)
DISP8_DATA: U10.P$22 (SDO), U14.P$2 (SDI)
DISP9_DATA: U14.P$22 (SDO)
DISPX_CLK: U1.44 (P3), U2.P$3 (CLK), U3.P$3 (CLK), U4.P$3 (CLK), U5.P$3 (CLK), U6.P$3 (CLK), U9.P$3 (CLK), U10.P$3 (CLK), U14.P$3 (CLK)
DISPX_LAT: U1.1 (P4), U2.P$4 (LE/DM1), U3.P$4 (LE/DM1), U4.P$4 (LE/DM1), U5.P$4 (LE/DM1), U6.P$4 (LE/DM1), U9.P$4 (LE/DM1), U10.P$4 (LE/DM1), U14.P$4 (LE/DM1)
ENCODER_A: C25.1, R18.2, U1.4 (P7)
ENCODER_B: C26.1, R19.1, U1.3 (P6)
GND: C1.2, C2.NEG, C3.NEG, C4.NEG, C5.NEG, C6.2, C7.2, C8.2, C9.2, C10.2, C11.2, C12.P$2, C13.P$2, C14.P$2, C15.P$2, C16.P$2, C17.1, C18.1, C19.1, C20.1, C22.1, C23.1, C24.2, C25.2, C26.2, EN1.C, GND.P$1, J1.4 (GND), L1.P$2, LCD1.P$18 (GND2), R1.1, R2.1, R3.1, R4.1, R5.1, R6.1, R7.1, R10.P$1, R15.1, SW1.1, SW2.1, SW3.1A, U1.5 (VSS), U1.6 (!BOE), U1.17 (VSS), U1.27 (VSS), U1.39 (VSS), U2.P$1 (VSS/GND), U2.P$21 (!OE/DM2), U2.PAD (VSS/GND), U3.P$1 (VSS/GND), U3.P$21 (!OE/DM2), U3.PAD (VSS/GND), U4.P$1 (VSS/GND), U4.P$21 (!OE/DM2), U4.PAD (VSS/GND), U5.P$1 (VSS/GND), U5.P$21 (!OE/DM2), U5.PAD (VSS/GND), U6.P$1 (VSS/GND), U6.P$21 (!OE/DM2), U6.PAD (VSS/GND), U7.1 (GND), U8.1 (GND), U9.P$1 (VSS/GND), U9.P$21 (!OE/DM2), U9.PAD (VSS/GND), U10.P$1 (VSS/GND), U10.P$21 (!OE/DM2), U10.PAD (VSS/GND), U11.1 (A0), U11.2 (A1), U11.3 (A2), U11.4 (GND), U11.7 (WP), U12.2 (GND), U13.5 (GND), U13.P$1 (GND), U14.P$1 (VSS/GND), U14.P$21 (!OE/DM2), U14.PAD (VSS/GND), X1.P$2 (GND), X1.P$4 (GND)
LCD_SCK: LCD1.P$16 (SCK), U1.43 (P2)
LCD_SI/SO: LCD1.P$19 (SI/SO), U1.41 (P0)
LCD_STB: LCD1.P$17 (STB), U1.42 (P1)
unnamed: R1.2, U2.P$23 (R-EXT)
unnamed: R2.2, U3.P$23 (R-EXT)
unnamed: R3.2, U4.P$23 (R-EXT)
unnamed: R4.2, U5.P$23 (R-EXT)
unnamed: R5.2, U6.P$23 (R-EXT)
unnamed: R6.2, U9.P$23 (R-EXT)
unnamed: D16.C (CATHODE), U9.P$5 (!OUT0)
unnamed: D15.C (CATHODE), U9.P$6 (!OUT1)
unnamed: D14.C (CATHODE), U9.P$7 (!OUT2)
unnamed: D13.C (CATHODE), U9.P$8 (!OUT3)
unnamed: D12.C (CATHODE), U9.P$9 (!OUT4)
unnamed: D17.C (CATHODE), U10.P$20 (!OUT15)
unnamed: D10.C (CATHODE), U9.P$11 (!OUT6)
unnamed: D9.C (CATHODE), U9.P$12 (!OUT7)
unnamed: D8.C (CATHODE), U9.P$13 (!OUT8)
unnamed: D7.C (CATHODE), U9.P$14 (!OUT9)
unnamed: D6.C (CATHODE), U9.P$15 (!OUT10)
unnamed: D5.C (CATHODE), U9.P$16 (!OUT11)
unnamed: D4.C (CATHODE), U9.P$17 (!OUT12)
unnamed: D3.C (CATHODE), U9.P$18 (!OUT13)
unnamed: D2.C (CATHODE), U9.P$19 (!OUT14)
unnamed: D1.C (CATHODE), U9.P$20 (!OUT15)
unnamed: R7.2, U10.P$23 (R-EXT)
unnamed: D18.C (CATHODE), U10.P$19 (!OUT14)
unnamed: D19.C (CATHODE), U10.P$18 (!OUT13)
unnamed: D20.C (CATHODE), U10.P$17 (!OUT12)
unnamed: D21.C (CATHODE), U10.P$16 (!OUT11)
unnamed: D22.C (CATHODE), U10.P$15 (!OUT10)
unnamed: D23.C (CATHODE), U10.P$14 (!OUT9)
unnamed: D24.C (CATHODE), U10.P$13 (!OUT8)
unnamed: D25.C (CATHODE), U10.P$12 (!OUT7)
unnamed: D26.C (CATHODE), U10.P$11 (!OUT6)
unnamed: D27.C (CATHODE), U10.P$10 (!OUT5)
unnamed: R8.P$2, U13.1 (USBDM)
unnamed: D11.C (CATHODE), U9.P$10 (!OUT5)
unnamed: R9.P$2, U13.12 (USBDP)
unnamed: C12.P$1, R8.P$1, U12.4 (I/O2B)
unnamed: C13.P$1, R9.P$1, U12.3 (I/O1B)
unnamed: R15.2, U14.P$23 (R-EXT)
unnamed: EN1.1, U14.P$5 (!OUT0)
unnamed: EN1.2, U14.P$6 (!OUT1)
unnamed: EN1.4, U14.P$7 (!OUT2)
unnamed: SW1.CATHODE_1, U14.P$8 (!OUT3)
unnamed: SW1.CATHODE_2, U14.P$9 (!OUT4)
unnamed: SW2.CATHODE_1, U14.P$10 (!OUT5)
unnamed: SW2.CATHODE_2, U14.P$11 (!OUT6)
unnamed: SW3.CATHODE_1, U14.P$12 (!OUT7)
unnamed: SW3.CATHODE_2, U14.P$13 (!OUT8)
unnamed: R20.2, SW1.3
unnamed: R21.2, SW2.3
unnamed: R22.2, SW3.2
P11: J2.1, U1.12 (P11)
P12: J2.2, U1.13 (P12)
P13: J2.3, U1.14 (P13)
P14: J2.4, U1.15 (P14)
P15: J2.5, U1.16 (P15)
P16: J2.6, U1.19 (P16)
P17: J2.7, U1.20 (P17)
P18: J2.8, U1.21 (P18)
P19: U1.22 (P19)
P20: U1.23 (P20)
P21: U1.24 (P21)
P22: U1.25 (P22)
P23: U1.26 (P23)
P24: U1.31 (P24)
P25: U1.32 (P25)
P26: U1.33 (P26)
P27: U1.34 (P27)
RES: C21.1, R14.1, U1.7 (!RES)
RX: U1.37 (P30), U13.10 (RXD)
SCL: R12.1, U1.35 (P28), U11.6 (SCL)
SDA: R13.1, U1.36 (P29), U11.5 (SDA)
SHIELD: J1.S1 (SLD), J1.S2 (SLD), L1.P$1
SW_1: SW1.4, U1.9 (P8)
SW_2: SW2.4, U1.10 (P9)
SW_3: SW3.3, U1.11 (P10)
TERMINAL_A: EN1.A, R16.1, R18.1
TERMINAL_B: EN1.B, R17.1, R19.2
TX: U1.38 (P31), U13.7 (TXD)
USB_!RST: C21.2, U13.8 (RTS#)
VBUS_SENSE: R10.P$2, R11.P$1, U13.6 (CBUS0)
VIN: 5V.P$1, C2.POS, C4.POS, LCD1.P$20 (VCC2), U7.2 (IN), U8.2 (IN)
V_USB_0: J1.1 (5V), R11.P$2, U12.5 (VB)
X0: U1.29 (X0), X1.P$3 (X1)
X1: U1.28 (X1), X1.P$1 (X0)

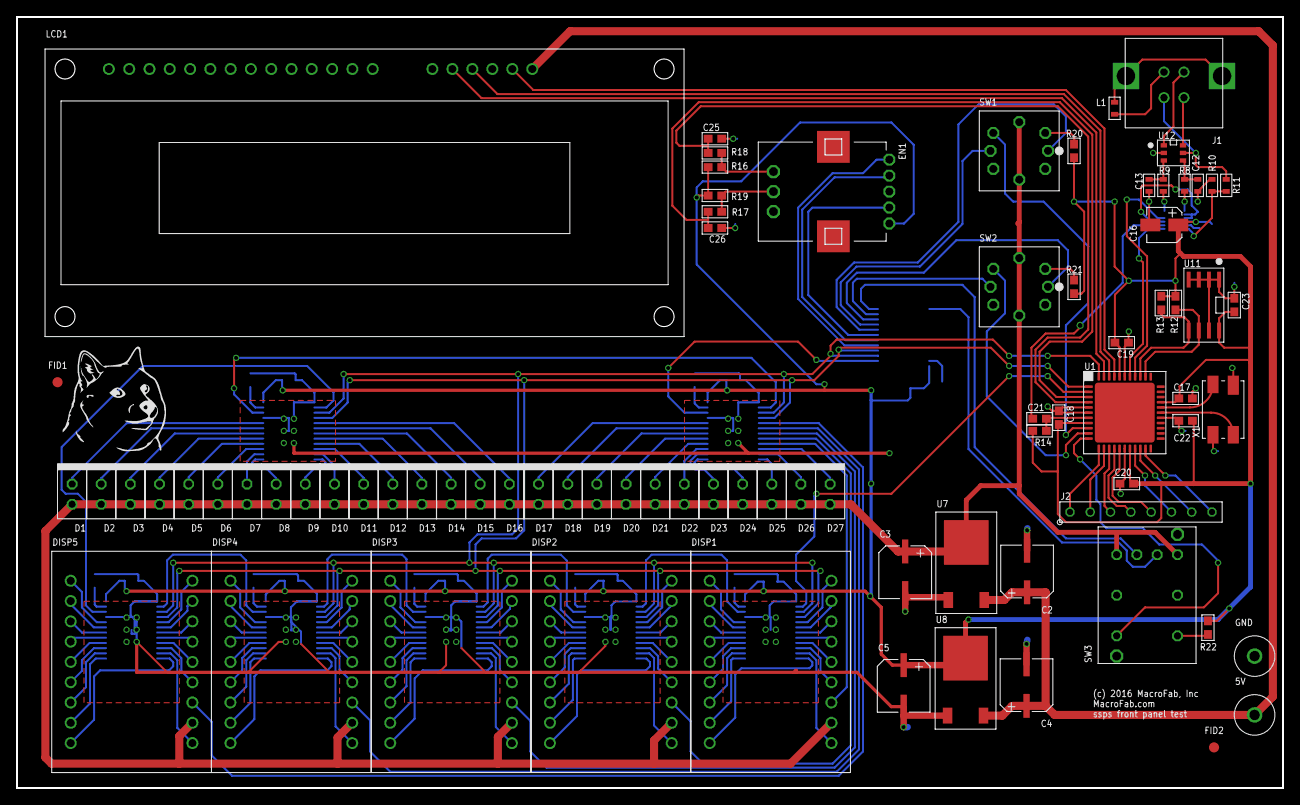
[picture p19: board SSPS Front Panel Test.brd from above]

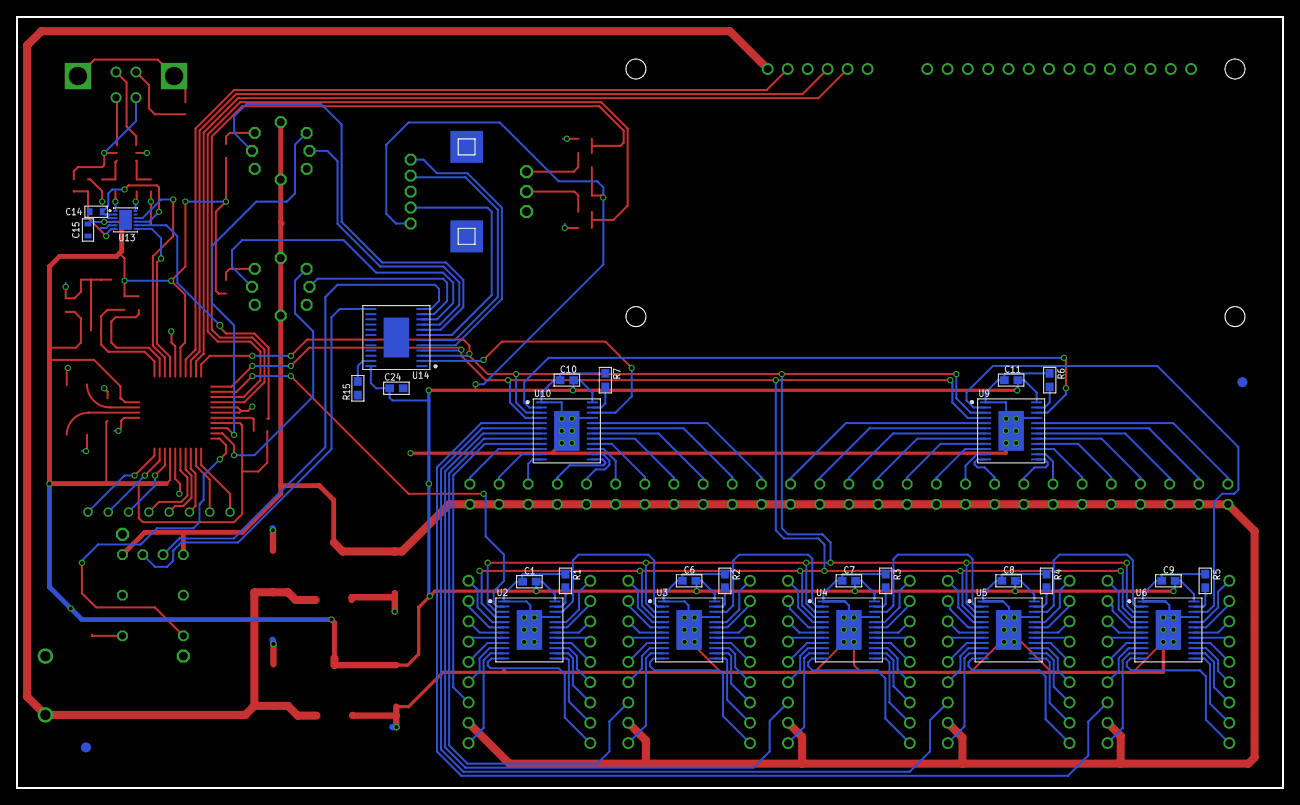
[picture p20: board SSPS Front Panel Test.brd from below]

Board: 2 copper layers, 158.5 x 96.5 mm, 108 parts (27 on the bottom side), 182 nets.

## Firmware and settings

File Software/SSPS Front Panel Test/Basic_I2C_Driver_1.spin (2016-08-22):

'' Basic I2C Routines  Version 1.3
'' Written by Michael Green and copyright (c) 2009
'' Permission is given to use this in any program for the Parallax
'' Propeller processor as long as this copyright notice is included.

'' Version: 1.0 - Initial version
''          1.1 - Corrected some comments
''          1.2 - Corrected example, added this list
''          1.3 - Added logic for non-memory devices

'' This is a minimal version of an I2C driver in SPIN.  It assumes
'' that the SDA pin is one higher than the SCL pin.  It assumes that
'' neither the SDA nor the SCL pins have pullups, so drives both.

'' These routines are primarily intended for reading and writing EEPROMs.
'' The low level I2C are provided for use with other devices, but the
'' read/write byte routines assume a standard I2C serial EEPROM with a
'' 16 bit device address register, paged writes, and acknowledge polling.

'' All of these read/write routines accept an EEPROM address up to 19
'' bits (512K) even though the EEPROM addressing scheme normally allows
'' for only 16 bits of addressing.  The upper 3 bits are used as part of
'' the device select code and these routines will take the upper 3 bits
'' of the address and "or" it with the supplied device select code bits
'' 3-1 which are used to select a particular EEPROM on an I2C bus.  There
'' are two schemes for selecting 64K "banks" in 128Kx8 EEPROMs.  Atmel's
'' 24LC1024 EEPROMs allow simple linear addressing up to 256Kx8 ($00000
'' to $3FFFF).  Microchip's 24LC1025 allows for up to 512Kx8, but in two
'' areas: $00000 to $3FFFF and $40000 to $7FFFF.  Each EEPROM provides
'' a 64K "bank" in each area.  See the device datasheets for details.

'' If bit 21 of the address value is non-zero, then bit 20 indicates how
'' many address bytes are to be sent to the device.  If bit 20 is zero,
'' no address is sent.  If bit 20 is a one, then a single address byte
'' is sent.
         
'' This will work with the boot EEPROM and does not require a pull-up
'' resistor on the SCL line (but does on the SDA line ... about 4.7K to
'' +3.3V).  According to the Philips I2C specification, both pull-ups
'' are required.  Many devices will tolerate the absence of a pull-up
'' on SCL.  Some may tolerate the absence of a pull-up on SDA as well.

'' Initialize may have to be called once at the beginning of your
'' program.  Sometimes an I2C device is left in an invalid state.  This
'' will reset the device to a known state so it will respond to the I2C
'' start transition (sent out by the i2cStart routine).

'' To read from or write to an EEPROM on pins 28/29 like the boot EEPROM:

'' CON
''   eepromAddress = $7000

'' VAR
''   byte buffer[32]

'' OBJ
''   i2c : "Basic_I2C_Driver"

'' PRI readIt
''   if i2c.ReadPage(i2c#BootPin, i2c#EEPROM, eepromAddress, @buffer, 32)
''     abort ' an error occurred during the read

'' PRI writeIt | startTime
''   if i2c.WritePage(i2c#BootPin, i2c#EEPROM, eepromAddress, @buffer, 32)
''     abort ' an error occured during the write
''   startTime := cnt ' prepare to check for a timeout
''   repeat while i2c.WriteWait(i2c#BootPin, i2c#EEPROM, eepromAddress)
''     if cnt - startTime > clkfreq / 10
''       abort ' waited more than a 1/10 second for the write to finish

'' Note that the read and write use something called paged reads/writes.
'' This means that any read using ReadPage must fit entirely in one
'' EEPROM if you have several attached to one set of pins.  For writes,
'' any write using i2cWritePage must fit entirely within a page of the
'' EEPROM.  Usually these pages are either 32, 64, 128 or 256 bytes in
'' size depending on the manufacturer and device type.  32 bytes is a
'' good limit for the number of bytes to be written at a time if you
'' don't know the specific page size (and the write must fit completely
'' within a multiple of the page size).  The WriteWait waits for the
'' write operation to complete.  Alternatively, you could wait for 5ms
'' since currently produced EEPROMs will finish within that time.

'' To read from an I2C device that uses a single register address byte,
'' you could use any of these methods and supply a device address as
'' follows:

'' i2c.ReadByte( <SCL pin #>, <device code>, <register> | i2c#OneAddr)

'' Similarly, to write to a device that doesn't use an address byte,
'' you'd use:

'' i2c.WriteByte( <SCL pin #>, <device code>, i2c#NoAddr)

CON
   ACK      = 0                        ' I2C Acknowledge
   NAK      = 1                        ' I2C No Acknowledge
   Xmit     = 0                        ' I2C Direction Transmit
   Recv     = 1                        ' I2C Direction Receive
   NoAddr   = $200000                  ' I2C Don't use register address
   OneAddr  = $300000                  ' I2C Use 8-bit register address

VAR
  byte SCL  
  byte SDA
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

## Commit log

2016-02-11 Schematic and board files for the OPA541 Breakout
2016-03-04 Started front panel design.
    [SSPS Front Panel.brd, SSPS Front Panel.sch]
2016-03-05 figuring out LEDS
    [SSPS Front Panel.brd, SSPS Front Panel.sch]
2016-03-21 Added simulation of Regulated power supply.
2016-03-22 Started modeling the chassis. Needs to be filled.
    [Enclosure.skp]
2016-03-24 Enclosure design done.
2016-05-03 Working on Front panel.
    [SSPS Front Panel.brd, SSPS Front Panel.sch]
2016-05-04 Layout for front panel update.
    [SSPS Front Panel.brd, SSPS Front Panel.sch]
2016-05-10 Front panel test layout almost complete.
    [SSPS Front Panel Test.brd, SSPS Front Panel Test.sch, SSPS Front Panel.brd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]
2016-05-11 Test for Front Panel of SSPS complete.
    [SSPS Front Panel Test.brd, SSPS Front Panel Test.sch]
2016-05-12 Fixed part numbers.
    [SSPS Front Panel Test.brd, SSPS Front Panel Test.sch]
2016-06-21 Fixed USB_!RST net...
    [SSPS Front Panel Test.brd, SSPS Front Panel Test.sch, SSPS Front Panel.dwg]
2016-06-29 SSPS Front Panel Test fixed.
    [SSPS Front Panel Test.brd, SSPS Front Panel Test.sch]
2016-06-30 Encoder working!
2016-08-11 Added Schematic and Layout files for the Analog board
    finished the single channel test board for the analog portion of the
    SSPS
2016-08-11 Cleaning file structure and adding files
    File structure was cleaned and the SSPS analog board added.
    [OPA541.drl, OPA541APBreakout.GBL, OPA541APBreakout.GBO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]
2016-08-12 Added Test code for analog board

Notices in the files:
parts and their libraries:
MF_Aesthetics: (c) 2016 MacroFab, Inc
